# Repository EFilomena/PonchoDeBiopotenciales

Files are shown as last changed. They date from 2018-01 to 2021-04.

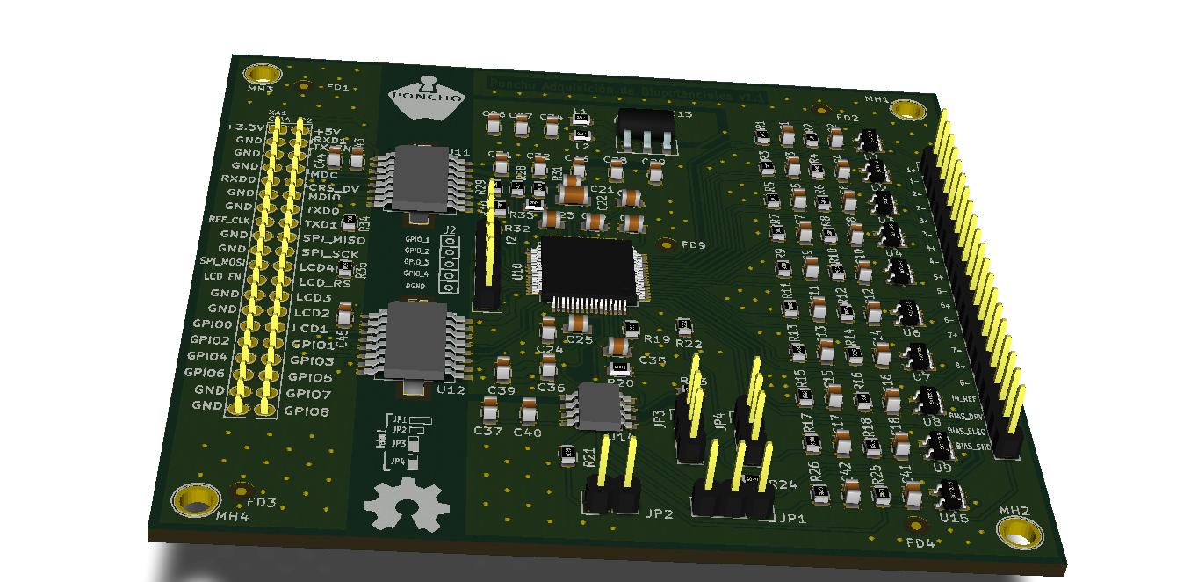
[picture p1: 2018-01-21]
Hardware/doc/PonchoBiopotenciales3d.jpg

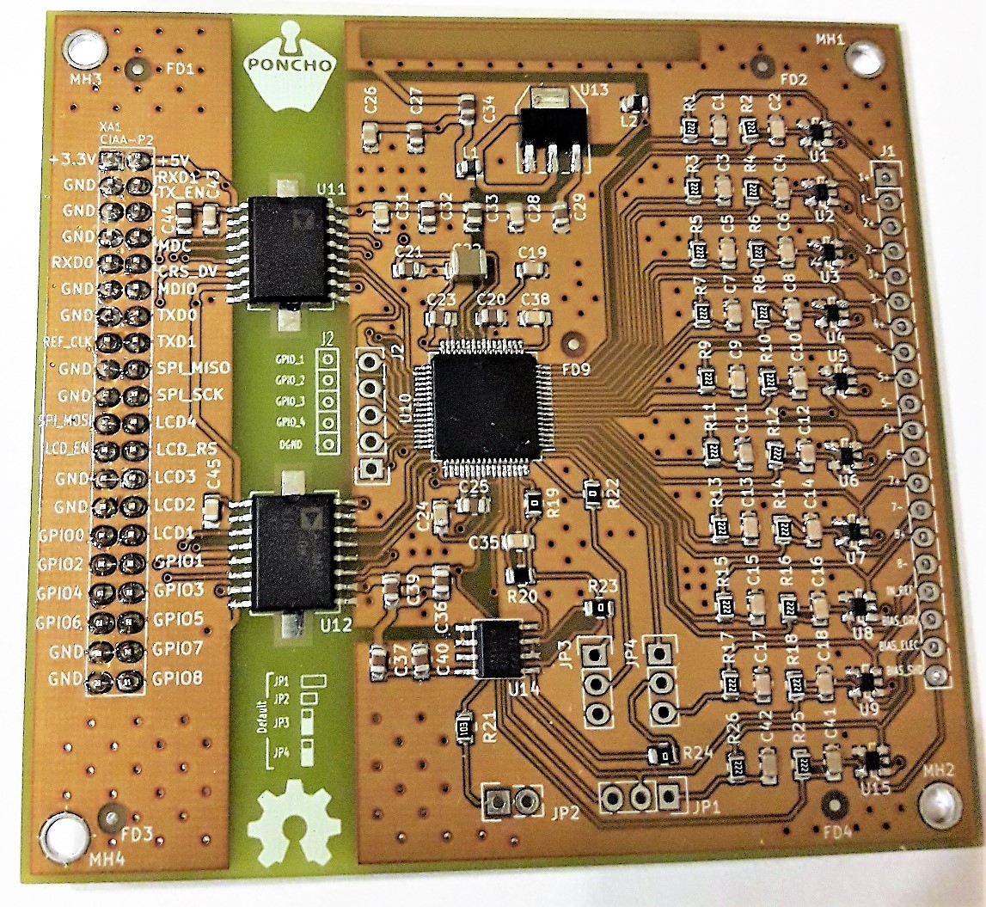
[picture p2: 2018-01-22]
Hardware/doc/Foto1.jpg

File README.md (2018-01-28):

# PonchoDeBiopotenciales

Este repositorio, contiene toda la información de desarrollo del poncho de adquisición de biopotenciales. 
Este poncho es parte del proyecto CIAA (http://www.proyecto-ciaa.com.ar/), y aplica fundamentalmente a la placa 
EDU-CIAA (http://www.proyecto-ciaa.com.ar/devwiki/doku.php?id=desarrollo:edu-ciaa:edu-ciaa-nxp). 

Permite la digitalización y registro de todo tipo de biopotenciales como: electrocardiograma, 
electroencefalograma, electromiograma, electrooculograma entre otros.

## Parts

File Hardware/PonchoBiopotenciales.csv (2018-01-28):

Source | D:/Repositorios/PonchoDeBiopotenciales/Hardware/PonchoBiopotenciales.sch
Kicad Rev | Eeschema 4.0.2-stable
Generated Date | 28/01/2018 7:24
Title | Poncho de AdquisiciÃ³n de Biopotenciales
Company | FIUNER
Revision | 1.1
Date Issue | lun 05 oct 2015
Comment | Bruno Javier Cesario - Gonzalo Cuenca - Eduardo Filomena (FIUNER)
Reference | Value | DescripciÃ³n | Fabricante | Nro de parte | Digikey | Footprint | Library | Library Ref | Cotización Digikey 01/2018
G2 | OSHWA | PonchoBiopotenciales | OSHWA |  |  |  |  |  | por 100 unidades
G1 | Logo_Poncho | PonchoBiopotenciales | Logo_Poncho
R1 | 2.2k | RES SMD 2.2K OHM 5% 1/8W 0805 | Yageo | RC0805JR-072K2L | 311-2.2KARCT-ND | 805 | PonchoBiopotenciales | R_Small | 0,0076
R2 | 2.2k | RES SMD 2.2K OHM 5% 1/8W 0805 | Yageo | RC0805JR-072K2L | 311-2.2KARCT-ND | 805 | PonchoBiopotenciales | R_Small | 0,0076
R4 | 2.2k | RES SMD 2.2K OHM 5% 1/8W 0805 | Yageo | RC0805JR-072K2L | 311-2.2KARCT-ND | 805 | PonchoBiopotenciales | R_Small | 0,0076
R3 | 2.2k | RES SMD 2.2K OHM 5% 1/8W 0805 | Yageo | RC0805JR-072K2L | 311-2.2KARCT-ND | 805 | PonchoBiopotenciales | R_Small | 0,0076
C1 | 1nF | CAP CER 1000PF 50V X7R 0805 | Kemet | C0805C102K5RACTU | 399-1147-1-ND | 805 | PonchoBiopotenciales | C | 0,019
C2 | 1nF | CAP CER 1000PF 50V X7R 0805 | Kemet | C0805C102K5RACTU | 399-1147-1-ND | 805 | PonchoBiopotenciales | C | 0,019
C3 | 1nF | CAP CER 1000PF 50V X7R 0805 | Kemet | C0805C102K5RACTU | 399-1147-1-ND | 805 | PonchoBiopotenciales | C | 0,019
C4 | 1nF | CAP CER 1000PF 50V X7R 0805 | Kemet | C0805C102K5RACTU | 399-1147-1-ND | 805 | PonchoBiopotenciales | C | 0,019
C5 | 1nF | CAP CER 1000PF 50V X7R 0805 | Kemet | C0805C102K5RACTU | 399-1147-1-ND | 805 | PonchoBiopotenciales | C | 0,019
C6 | 1nF | CAP CER 1000PF 50V X7R 0805 | Kemet | C0805C102K5RACTU | 399-1147-1-ND | 805 | PonchoBiopotenciales | C | 0,019
C7 | 1nF | CAP CER 1000PF 50V X7R 0805 | Kemet | C0805C102K5RACTU | 399-1147-1-ND | 805 | PonchoBiopotenciales | C | 0,019
C8 | 1nF | CAP CER 1000PF 50V X7R 0805 | Kemet | C0805C102K5RACTU | 399-1147-1-ND | 805 | PonchoBiopotenciales | C | 0,019
C9 | 1nF | CAP CER 1000PF 50V X7R 0805 | Kemet | C0805C102K5RACTU | 399-1147-1-ND | 805 | PonchoBiopotenciales | C | 0,019
C10 | 1nF | CAP CER 1000PF 50V X7R 0805 | Kemet | C0805C102K5RACTU | 399-1147-1-ND | 805 | PonchoBiopotenciales | C | 0,019
C11 | 1nF | CAP CER 1000PF 50V X7R 0805 | Kemet | C0805C102K5RACTU | 399-1147-1-ND | 805 | PonchoBiopotenciales | C | 0,019
C12 | 1nF | CAP CER 1000PF 50V X7R 0805 | Kemet | C0805C102K5RACTU | 399-1147-1-ND | 805 | PonchoBiopotenciales | C | 0,019
C13 | 1nF | CAP CER 1000PF 50V X7R 0805 | Kemet | C0805C102K5RACTU | 399-1147-1-ND | 805 | PonchoBiopotenciales | C | 0,019
C14 | 1nF | CAP CER 1000PF 50V X7R 0805 | Kemet | C0805C102K5RACTU | 399-1147-1-ND | 805 | PonchoBiopotenciales | C | 0,019
C15 | 1nF | CAP CER 1000PF 50V X7R 0805 | Kemet | C0805C102K5RACTU | 399-1147-1-ND | 805 | PonchoBiopotenciales | C | 0,019
C16 | 1nF | CAP CER 1000PF 50V X7R 0805 | Kemet | C0805C102K5RACTU | 399-1147-1-ND | 805 | PonchoBiopotenciales | C | 0,019
R13 | 2.2k | RES SMD 2.2K OHM 5% 1/8W 0805 | Yageo | RC0805JR-072K2L | 311-2.2KARCT-ND | 805 | PonchoBiopotenciales | R_Small | 0,0076
R14 | 2.2k | RES SMD 2.2K OHM 5% 1/8W 0805 | Yageo | RC0805JR-072K2L | 311-2.2KARCT-ND | 805 | PonchoBiopotenciales | R_Small | 0,0076
R16 | 2.2k | RES SMD 2.2K OHM 5% 1/8W 0805 | Yageo | RC0805JR-072K2L | 311-2.2KARCT-ND | 805 | PonchoBiopotenciales | R_Small | 0,0076
R15 | 2.2k | RES SMD 2.2K OHM 5% 1/8W 0805 | Yageo | RC0805JR-072K2L | 311-2.2KARCT-ND | 805 | PonchoBiopotenciales | R_Small | 0,0076
R17 | 2.2k | RES SMD 2.2K OHM 5% 1/8W 0805 | Yageo | RC0805JR-072K2L | 311-2.2KARCT-ND | 805 | PonchoBiopotenciales | R_Small | 0,0076
R18 | 2.2k | RES SMD 2.2K OHM 5% 1/8W 0805 | Yageo | RC0805JR-072K2L | 311-2.2KARCT-ND | 805 | PonchoBiopotenciales | R_Small | 0,0076
C17 | 1nF | CAP CER 1000PF 50V X7R 0805 | Kemet | C0805C102K5RACTU | 399-1147-1-ND | 805 | PonchoBiopotenciales | C | 0,019
C18 | 1nF | CAP CER 1000PF 50V X7R 0805 | Kemet | C0805C102K5RACTU | 399-1147-1-ND | 805 | PonchoBiopotenciales | C | 0,019
U1 | TPD2E001 | TVS DIODE 5.5VWM 100VC SOT5 | Texas Instruments | TPD2E001DRLR | 296-21883-1-ND | SOT-553 | PonchoBiopotenciales | TPD2E001 | 0,37
U2 | TPD2E001 | TVS DIODE 5.5VWM 100VC SOT5 | Texas Instruments | TPD2E001DRLR | 296-21883-1-ND | SOT-553 | PonchoBiopotenciales | TPD2E001 | 0,37
U3 | TPD2E001 | TVS DIODE 5.5VWM 100VC SOT5 | Texas Instruments | TPD2E001DRLR | 296-21883-1-ND | SOT-553 | PonchoBiopotenciales | TPD2E001 | 0,37
U4 | TPD2E001 | TVS DIODE 5.5VWM 100VC SOT5 | Texas Instruments | TPD2E001DRLR | 296-21883-1-ND | SOT-553 | PonchoBiopotenciales | TPD2E001 | 0,37
U5 | TPD2E001 | TVS DIODE 5.5VWM 100VC SOT5 | Texas Instruments | TPD2E001DRLR | 296-21883-1-ND | SOT-553 | PonchoBiopotenciales | TPD2E001 | 0,37
U6 | TPD2E001 | TVS DIODE 5.5VWM 100VC SOT5 | Texas Instruments | TPD2E001DRLR | 296-21883-1-ND | SOT-553 | PonchoBiopotenciales | TPD2E001 | 0,37
U7 | TPD2E001 | TVS DIODE 5.5VWM 100VC SOT5 | Texas Instruments | TPD2E001DRLR | 296-21883-1-ND | SOT-553 | PonchoBiopotenciales | TPD2E001 | 0,37
U8 | TPD2E001 | TVS DIODE 5.5VWM 100VC SOT5 | Texas Instruments | TPD2E001DRLR | 296-21883-1-ND | SOT-553 | PonchoBiopotenciales | TPD2E001 | 0,37
U9 | TPD2E001 | TVS DIODE 5.5VWM 100VC SOT5 | Texas Instruments | TPD2E001DRLR | 296-21883-1-ND | SOT-553 | PonchoBiopotenciales | TPD2E001 | 0,37
U15 | TPD2E001 | TVS DIODE 5.5VWM 100VC SOT5 | Texas Instruments | TPD2E001DRLR | 296-21883-1-ND | SOT-553 | PonchoBiopotenciales | TPD2E001 | 0,37
R26 | 2.2k | RES SMD 2.2K OHM 5% 1/8W 0805 | Yageo | RC0805JR-072K2L | 311-2.2KARCT-ND | 805 | PonchoBiopotenciales | R_Small | 0,0076
R25 | 2.2k | RES SMD 2.2K OHM 5% 1/8W 0805 | Yageo | RC0805JR-072K2L | 311-2.2KARCT-ND | 805 | PonchoBiopotenciales | R_Small | 0,0076
C41 | 1nF | CAP CER 1000PF 50V X7R 0805 | Kemet | C0805C102K5RACTU | 399-1147-1-ND | 805 | PonchoBiopotenciales | C | 0,019
C42 | 1nF | CAP CER 1000PF 50V X7R 0805 | Kemet | C0805C102K5RACTU | 399-1147-1-ND | 805 | PonchoBiopotenciales | C | 0,019
J1 | 20POS SIL VERTICAL PIN HEADER | Cuttable Connector 0.100" (2.54mm) Through Hole Tin | Harwin Inc. | M20-9992046 | 952-1902-ND |  | PonchoBiopotenciales | CONN_01X20 | 0,45
R12 | 2.2k | RES SMD 2.2K OHM 5% 1/8W 0805 | Yageo | RC0805JR-072K2L | 311-2.2KARCT-ND | 805 | PonchoBiopotenciales | R_Small | 0,0076
R11 | 2.2k | RES SMD 2.2K OHM 5% 1/8W 0805 | Yageo | RC0805JR-072K2L | 311-2.2KARCT-ND | 805 | PonchoBiopotenciales | R_Small | 0,0076
R10 | 2.2k | RES SMD 2.2K OHM 5% 1/8W 0805 | Yageo | RC0805JR-072K2L | 311-2.2KARCT-ND | 805 | PonchoBiopotenciales | R_Small | 0,0076
R8 | 2.2k | RES SMD 2.2K OHM 5% 1/8W 0805 | Yageo | RC0805JR-072K2L | 311-2.2KARCT-ND | 805 | PonchoBiopotenciales | R_Small | 0,0076
R7 | 2.2k | RES SMD 2.2K OHM 5% 1/8W 0805 | Yageo | RC0805JR-072K2L | 311-2.2KARCT-ND | 805 | PonchoBiopotenciales | R_Small | 0,0076
R6 | 2.2k | RES SMD 2.2K OHM 5% 1/8W 0805 | Yageo | RC0805JR-072K2L | 311-2.2KARCT-ND | 805 | PonchoBiopotenciales | R_Small | 0,0076
R5 | 2.2k | RES SMD 2.2K OHM 5% 1/8W 0805 | Yageo | RC0805JR-072K2L | 311-2.2KARCT-ND | 805 | PonchoBiopotenciales | R_Small | 0,0076
R9 | 2.2k | RES SMD 2.2K OHM 5% 1/8W 0805 | Yageo | RC0805JR-072K2L | 311-2.2KARCT-ND | 805 | PonchoBiopotenciales | R_Small | 0,0076
U10 | ADS1299 | IC AFE 8-CH 24BIT 64TQFP | Texas Instruments | ADS1299IPAG | 296-35009-ND | 64-TQFP | PonchoBiopotenciales | ADS1299 | 46,48
C19 | 0.1uF | CAP CER 0.1UF 50V X7R 0805 | Kemet | C0805C104J5RACTU | 399-1171-1-ND | 0805 (2012 Metric) | PonchoBiopotenciales | C | 0,06
C20 | 10uF | CAP CER 10UF 25V X5R 0805 | Murata Electronics North America | GRM219R61E106KA12D | 490-7207-1-ND | 0805 (2012 Metric) | PonchoBiopotenciales | C | 0,1
C21 | 1uF | CAP CER 1UF 16V X7R 0805 | Kemet | C0805C105K4RACTU | 399-1284-1-ND | 0805 (2012 Metric) | PonchoBiopotenciales | C | 0,04
C23 | 1uF | CAP CER 1UF 16V X7R 0805 | Kemet | C0805C105K4RACTU | 399-1284-1-ND | 0805 (2012 Metric) | PonchoBiopotenciales | C | 0,04
C22 | 100uF | CAP CER 100UF 10V X5R 1210 | Kemet | C1210C107M8PACTU | 399-11631-1-ND | 1210 (3225 Metric) | PonchoBiopotenciales | C | 0,78
C24 | 0.1uF | CAP CER 0.1UF 50V X7R 0805 | Kemet | C0805C104J5RACTU | 399-1171-1-ND | 0805 (2012 Metric) | PonchoBiopotenciales | C | 0,06
C25 | 1uF | CAP CER 1UF 16V X7R 0805 | Kemet | C0805C105K4RACTU | 399-1284-1-ND | 0805 (2012 Metric) | PonchoBiopotenciales | C | 0,04
C26 | 0.1uF | CAP CER 0.1UF 50V X7R 0805 | Kemet | C0805C104J5RACTU | 399-1171-1-ND | 0805 (2012 Metric) | PonchoBiopotenciales | C | 0,06
C27 | 1uF | CAP CER 1UF 16V X7R 0805 | Kemet | C0805C105K4RACTU | 399-1284-1-ND | 0805 (2012 Metric) | PonchoBiopotenciales | C | 0,04
C28 | 0.1uF | CAP CER 0.1UF 50V X7R 0805 | Kemet | C0805C104J5RACTU | 399-1171-1-ND | 0805 (2012 Metric) | PonchoBiopotenciales | C | 0,06
C29 | 1uF | CAP CER 1UF 16V X7R 0805 | Kemet | C0805C105K4RACTU | 399-1284-1-ND | 0805 (2012 Metric) | PonchoBiopotenciales | C | 0,06
R19 | 0 | RES SMD 0 OHM JUMPER 1/8W 0805 | Yageo | RC0805JR-070RL | 311-0.0ARCT-ND | 0805 (2012 Metric) | PonchoBiopotenciales | R_Small | 0,007
R20 | 390k | RES SMD 390K OHM 5% 1/8W 0805 | Yageo | RC0805JR-07390KL | 311-390KARCT-ND | 0805 (2012 Metric) | PonchoBiopotenciales | R_Small | 0,007
C35 | 0.01uF | CAP CER 10000PF 50V X7R 0805 | Kemet | C0805C103K5RACTU | 399-1158-1-ND | 0805 (2012 Metric) | PonchoBiopotenciales | C | 0,017
JP2 | JUMPER | CONN HEADER VERT SGL 20POS GOLD | 3M | 961120-6404-AR | 3M9457-20-ND |  | PonchoBiopotenciales | JUMPER | 1,2
JP1 | JUMPER3 | CONN HEADER VERT SGL 20POS GOLD | 3M | 961120-6404-AR | 3M9457-20-ND |  | PonchoBiopotenciales | JUMPER3 | 1,2
U14 | OPA2376 | IC OPAMP GP 5.5MHZ RRO 8SOIC | Texas Instruments | OPA2376AIDR | 296-22564-1-ND | 8-SOIC (0.154" 3.90mm Width) | PonchoBiopotenciales | OPA2376 | 1,8
R21 | 10k | RES SMD 10K OHM 5% 1/8W 0805 | Yageo | RC0805JR-0710KL | 311-10KARCT-ND | 0805 (2012 Metric) | PonchoBiopotenciales | R_Small | 0,07
C36 | 1uF | CAP CER 1UF 16V X7R 0805 | Kemet | C0805C105K4RACTU | 399-1284-1-ND | 0805 (2012 Metric) | PonchoBiopotenciales | C | 0,07
C37 | 1uF | CAP CER 1UF 16V X7R 0805 | Kemet | C0805C105K4RACTU | 399-1284-1-ND | 0805 (2012 Metric) | PonchoBiopotenciales | C | 0,07
JP3 | JUMPER3 | CONN HEADER VERT SGL 20POS GOLD | 3M | 961120-6404-AR | 3M9457-20-ND |  | PonchoBiopotenciales | JUMPER3 | 1,2
R23 | 0 | RES SMD 0 OHM JUMPER 1/8W 0805 | Yageo | RC0805JR-070RL | 311-0.0ARCT-ND | 0805 (2012 Metric) | PonchoBiopotenciales | R_Small | 0,007
R22 | 0 | RES SMD 0 OHM JUMPER 1/8W 0805 | Yageo | RC0805JR-070RL | 311-0.0ARCT-ND | 0805 (2012 Metric) | PonchoBiopotenciales | R_Small | 0,007
C38 | 1nF | CAP CER 1000PF 50V X7R 0805 | Kemet | C0805C102K5RACTU | 399-1147-1-ND | 0805 (2012 Metric) | PonchoBiopotenciales | C | 0,019
R24 | 0 | RES SMD 0 OHM JUMPER 1/8W 0805 | Yageo | RC0805JR-070RL | 311-0.0ARCT-ND | 0805 (2012 Metric) | PonchoBiopotenciales | R_Small | 0,007
JP4 | JUMPER3 | CONN HEADER VERT SGL 20POS GOLD | 3M | 961120-6404-AR | 3M9457-20-ND |  | PonchoBiopotenciales | JUMPER3 | 1,2
C39 | 1uF | CAP CER 1UF 16V X7R 0805 | Kemet | C0805C105K4RACTU | 399-1284-1-ND | 0805 (2012 Metric) | PonchoBiopotenciales | C | 0,06
C40 | 1uF | CAP CER 1UF 16V X7R 0805 | Kemet | C0805C105K4RACTU | 399-1284-1-ND | 0805 (2012 Metric) | PonchoBiopotenciales | C | 0,06
J2 | IOs MultipropÃ³sito | CONN HEADER VERT SGL 20POS GOLD | 3M | 961120-6404-AR | 3M9457-20-ND |  | PonchoBiopotenciales | CONN_01X05 | 1,2
Jumper_STD1 | J_STD | PonchoBiopotenciales | J_STD
Jumper_Config1 | J_CFG | PonchoBiopotenciales | J_CFG
C31 | 0.1uF | CAP CER 0.1UF 50V X7R 0805 | Kemet | C0805C104J5RACTU | 399-1171-1-ND | 0805 (2012 Metric) | PonchoBiopotenciales | C | 0,06
C32 | 10uF | CAP CER 10UF 25V X5R 0805 | Murata Electronics North America | GRM219R61E106KA12D | 490-7207-1-ND | 0805 (2012 Metric) | PonchoBiopotenciales | C | 0,06
U11 | ADuM6401 | DGTL ISO 5KV 4CH GEN PURP 16SOIC | Analog Devices Inc | ADUM6401CRWZ | ADUM6401CRWZ-ND | 16-SOIC (0.295" 7.50mm Width) | PonchoBiopotenciales | ADuM6401-RESCUE-PonchoERG | 14,6
U12 | ADuM2401 | DGTL ISO 5KV 4CH GEN PURP 16SOIC | Analog Devices Inc. | ADUM2401ARWZ-RL | ADUM2401ARWZ-RLCT-ND | 16-SOIC (0.295" 7.50mm Width) | PonchoBiopotenciales | ADuM2401 | 5,99
XA1 | Conn_Poncho2P_2x_20x2 | CONN HEADER .100" DUAL STR 40POS | Sullins Connector Solutions | PRPC020DAAN-RC | S2011EC-20-ND |  | PonchoBiopotenciales | Conn_Poncho2P_2x_20x2 | 0,68
C43 | 0.1uF | CAP CER 0.1UF 50V X7R 0805 | Kemet | C0805C104J5RACTU | 399-1171-1-ND | 0805 (2012 Metric) | PonchoBiopotenciales | C | 0,06
C44 | 10uF | CAP CER 10UF 25V X5R 0805 | Murata Electronics North America | GRM219R61E106KA12D | 490-7207-1-ND | 0805 (2012 Metric) | PonchoBiopotenciales | C | 0,06
C45 | 0.1uF | CAP CER 0.1UF 50V X7R 0805 | Kemet | C0805C104J5RACTU | 399-1171-1-ND | 0805 (2012 Metric) | PonchoBiopotenciales | C | 0,06
SC_2 | Slot_2 | PonchoBiopotenciales | Fiducial
SC_1 | Slot_1 | PonchoBiopotenciales | Fiducial
R28 | 1k | RES SMD 1K OHM 5% 1/8W 0805 | Yageo | RC0805JR-071KL | 311-1.0KARCT-ND | 0805 (2012 Metric) | PonchoBiopotenciales | R_Small | 0,007
R29 | 1k | RES SMD 1K OHM 5% 1/8W 0805 | Yageo | RC0805JR-071KL | 311-1.0KARCT-ND | 0805 (2012 Metric) | PonchoBiopotenciales | R_Small | 0,007
R30 | 1k | RES SMD 1K OHM 5% 1/8W 0805 | Yageo | RC0805JR-071KL | 311-1.0KARCT-ND | 0805 (2012 Metric) | PonchoBiopotenciales | R_Small | 0,007
R31 | 1.8k | RES SMD 1.8K OHM 5% 1/8W 0805 | Yageo | RC0805JR-071K8L | 311-1.8KARCT-ND | 0805 (2012 Metric) | PonchoBiopotenciales | R_Small | 0,007
R32 | 1.8k | RES SMD 1.8K OHM 5% 1/8W 0805 | Yageo | RC0805JR-071K8L | 311-1.8KARCT-ND | 0805 (2012 Metric) | PonchoBiopotenciales | R_Small | 0,007
R35 | 1.8k | RES SMD 1.8K OHM 5% 1/8W 0805 | Yageo | RC0805JR-071K8L | 311-1.8KARCT-ND | 0805 (2012 Metric) | PonchoBiopotenciales | R_Small | 0,007
R34 | 1k | RES SMD 1K OHM 5% 1/8W 0805 | Yageo | RC0805JR-071KL | 311-1.0KARCT-ND | 0805 (2012 Metric) | PonchoBiopotenciales | R_Small | 0,007
R33 | 1.8k | RES SMD 1.8K OHM 5% 1/8W 0805 | Yageo | RC0805JR-071K8L | 311-1.8KARCT-ND | 0805 (2012 Metric) | PonchoBiopotenciales | R_Small | 0,007
U13 | NCP1117ST33T3G | IC REG LINEAR 3.3V 1A SOT223 | ON Semiconductor | NCP1117ST33T3G | NCP1117ST33T3GOSCT-ND | SOT-223 | PonchoBiopotenciales | NCP1117ST33T3G | 0,3
L1 | HZ0805E601R-10 | FERRITE BEAD 600 OHM 0805 1LN | Laird-Signal Integrity Products | HZ0805E601R-10 | 240-2399-1-ND | 0805 (2012 Metric) | PonchoBiopotenciales | HZ0805E601R-10 | 0,04
L2 | HZ0805E601R-10 | FERRITE BEAD 600 OHM 0805 1LN | Laird-Signal Integrity Products | HZ0805E601R-10 | 240-2399-1-ND | 0805 (2012 Metric) | PonchoBiopotenciales | HZ0805E601R-10 | 0,04
C33 | 10uF | CAP CER 10UF 25V X5R 0805 | Murata Electronics North America | GRM219R61E106KA12D | 490-7207-1-ND | 0805 (2012 Metric) | PonchoBiopotenciales | C | 0,1
C34 | 10uF | CAP CER 10UF 25V X5R 0805 | Murata Electronics North America | GRM219R61E106KA12D | 490-7207-1-ND | 0805 (2012 Metric) | PonchoBiopotenciales | C | 0,1
FD8 | Fiducial | PonchoBiopotenciales | Fiducial
FD7 | Fiducial | PonchoBiopotenciales | Fiducial |  |  |  |  |  | 82,909
FD6 | Fiducial | PonchoBiopotenciales | Fiducial
FD5 | Fiducial | PonchoBiopotenciales | Fiducial
FD9 | Fiducial | PonchoBiopotenciales | Fiducial
MH1 | PCB_HOLE | PonchoBiopotenciales | PCB_HOLE
MH4 | PCB_HOLE | PonchoBiopotenciales | PCB_HOLE
MH3 | PCB_HOLE | PonchoBiopotenciales | PCB_HOLE
MH2 | PCB_HOLE | PonchoBiopotenciales | PCB_HOLE
FD4 | Fiducial | PonchoBiopotenciales | Fiducial
FD3 | Fiducial | PonchoBiopotenciales | Fiducial
FD2 | Fiducial | PonchoBiopotenciales | Fiducial
FD1 | Fiducial | PonchoBiopotenciales | Fiducial

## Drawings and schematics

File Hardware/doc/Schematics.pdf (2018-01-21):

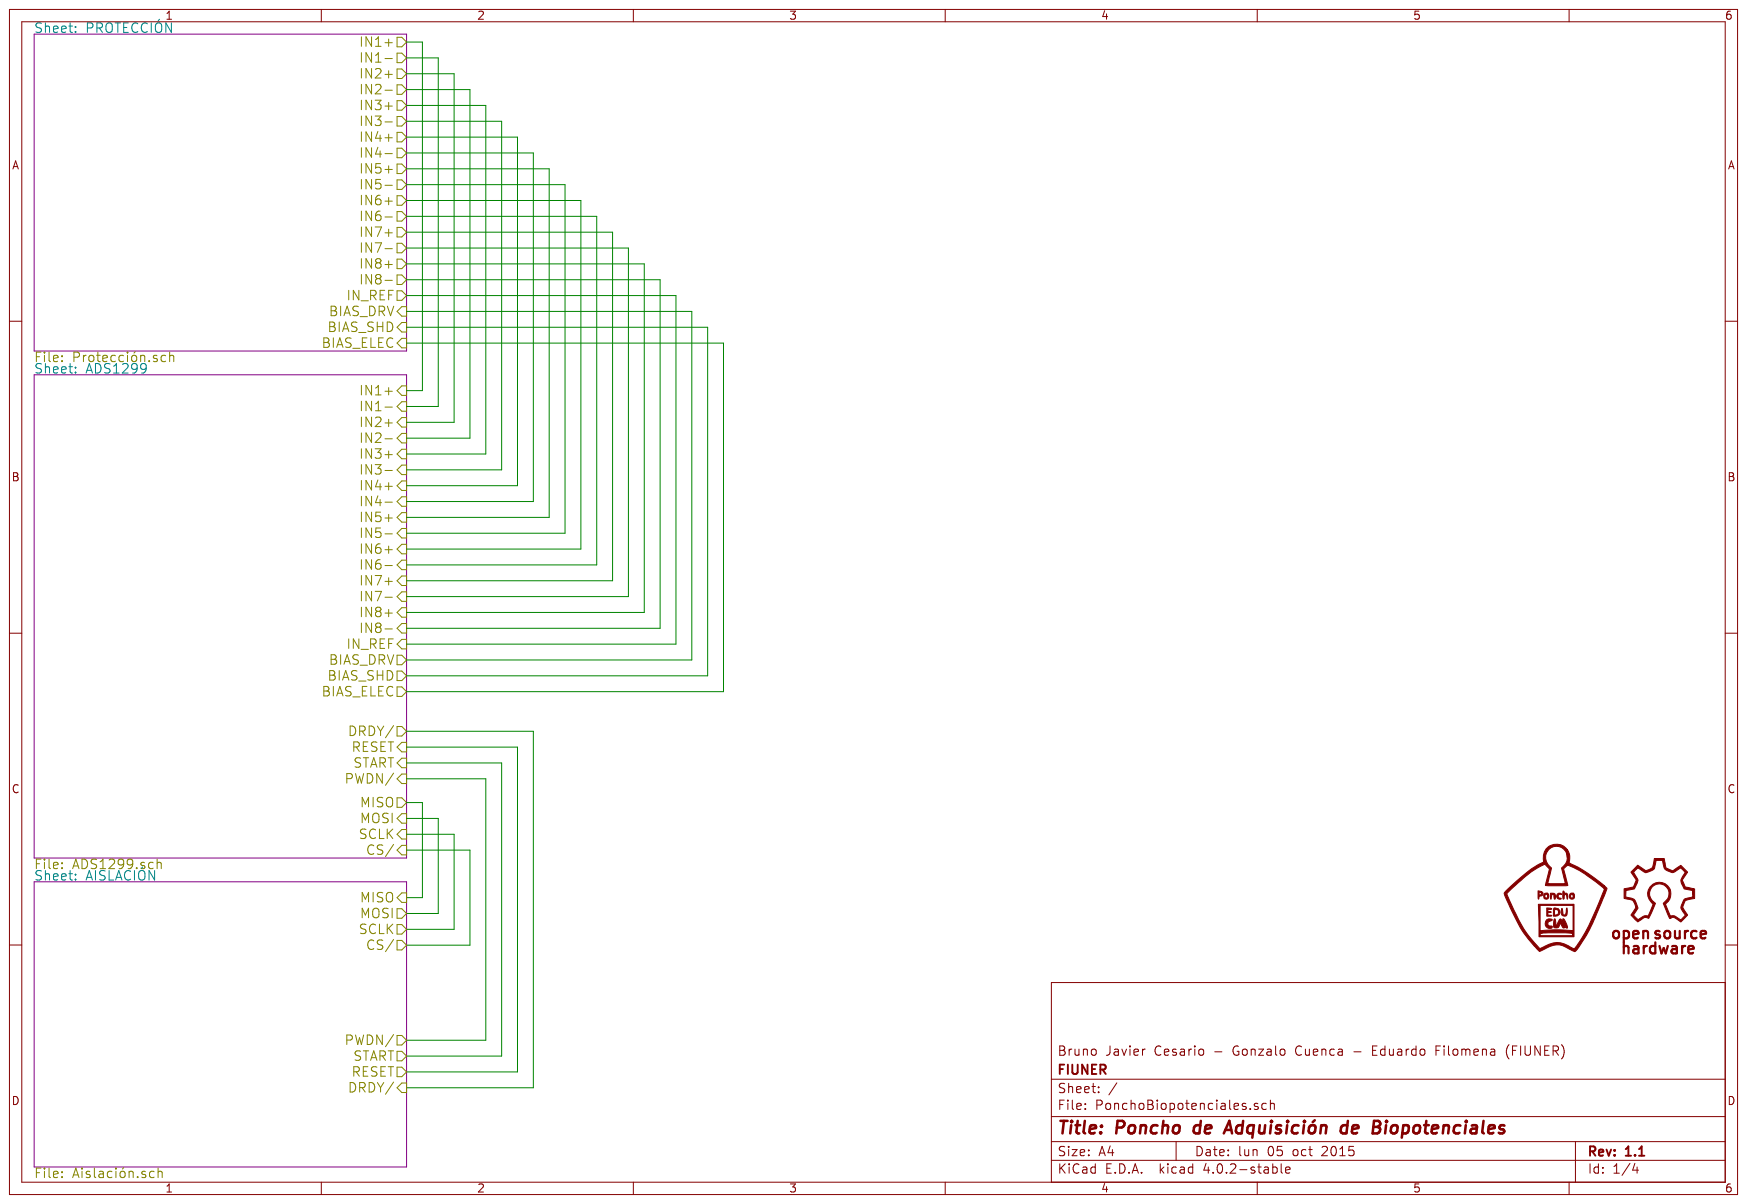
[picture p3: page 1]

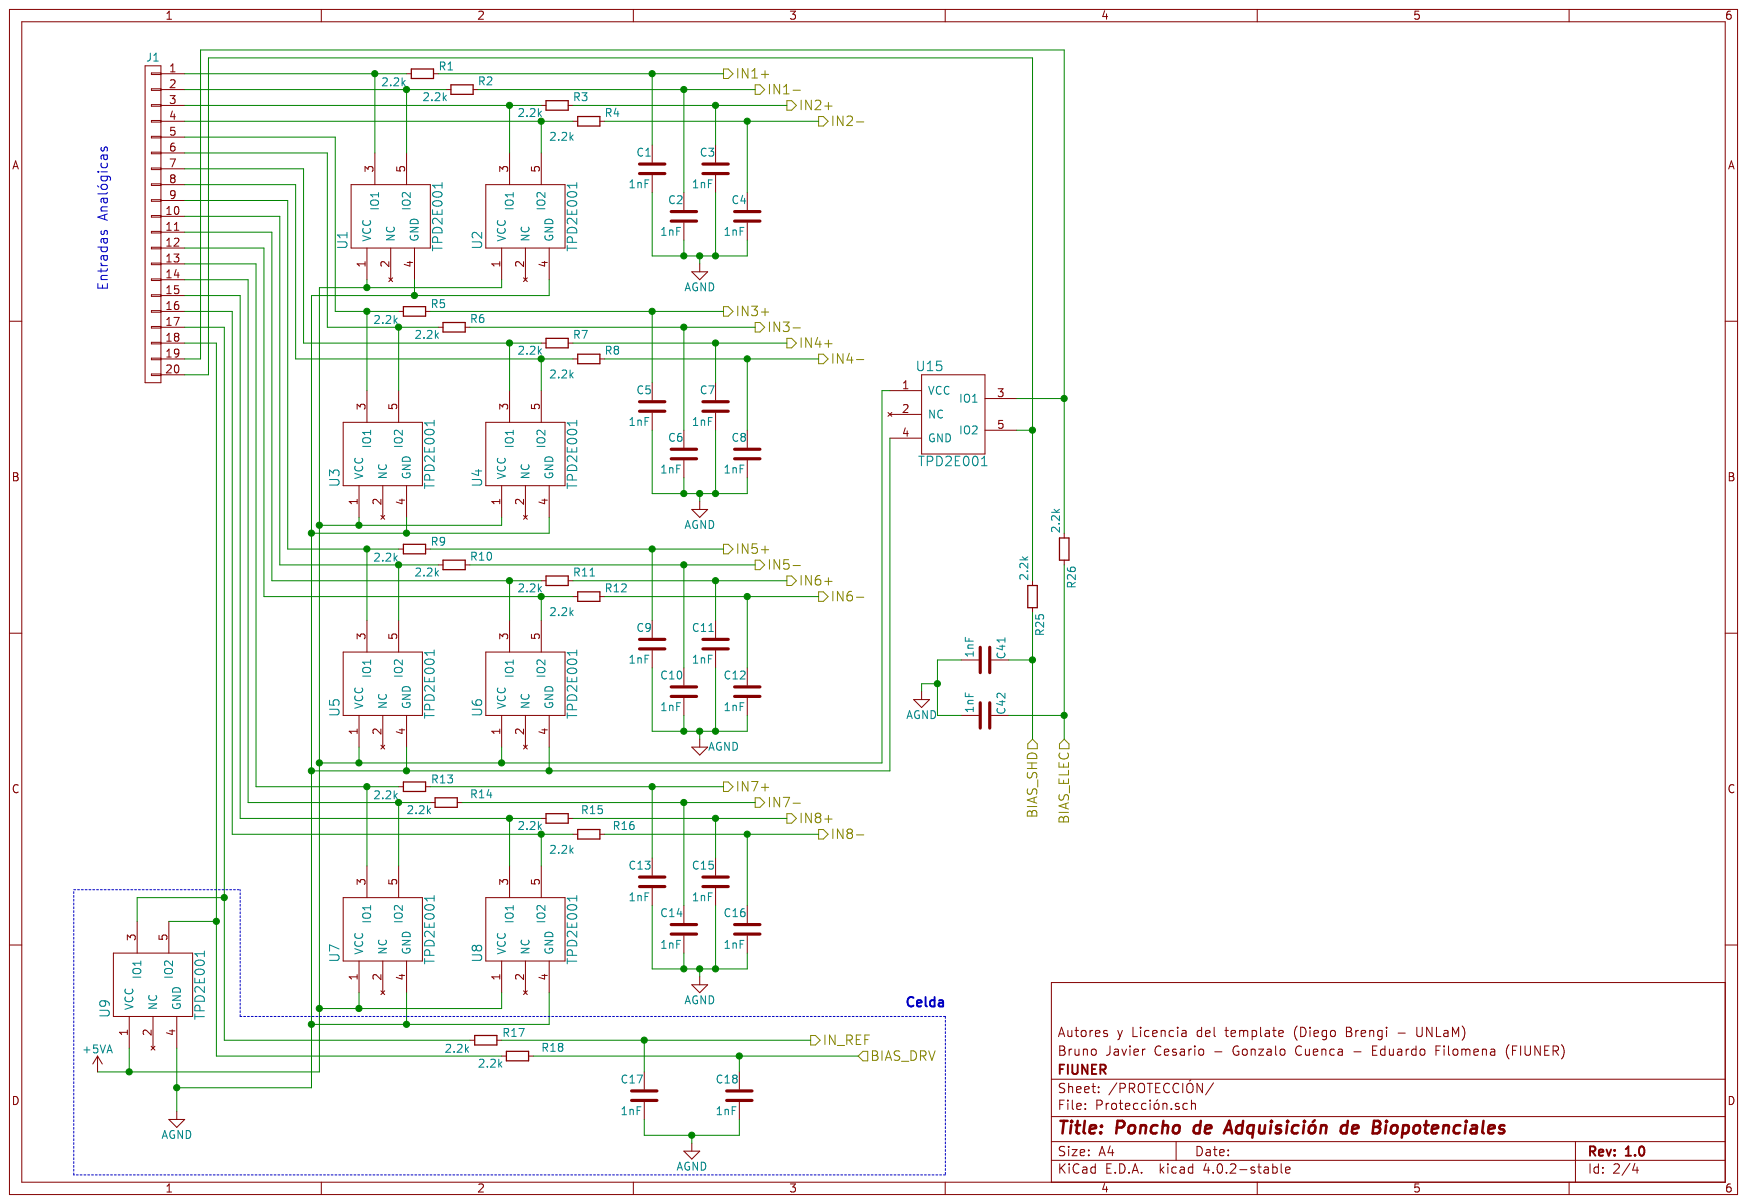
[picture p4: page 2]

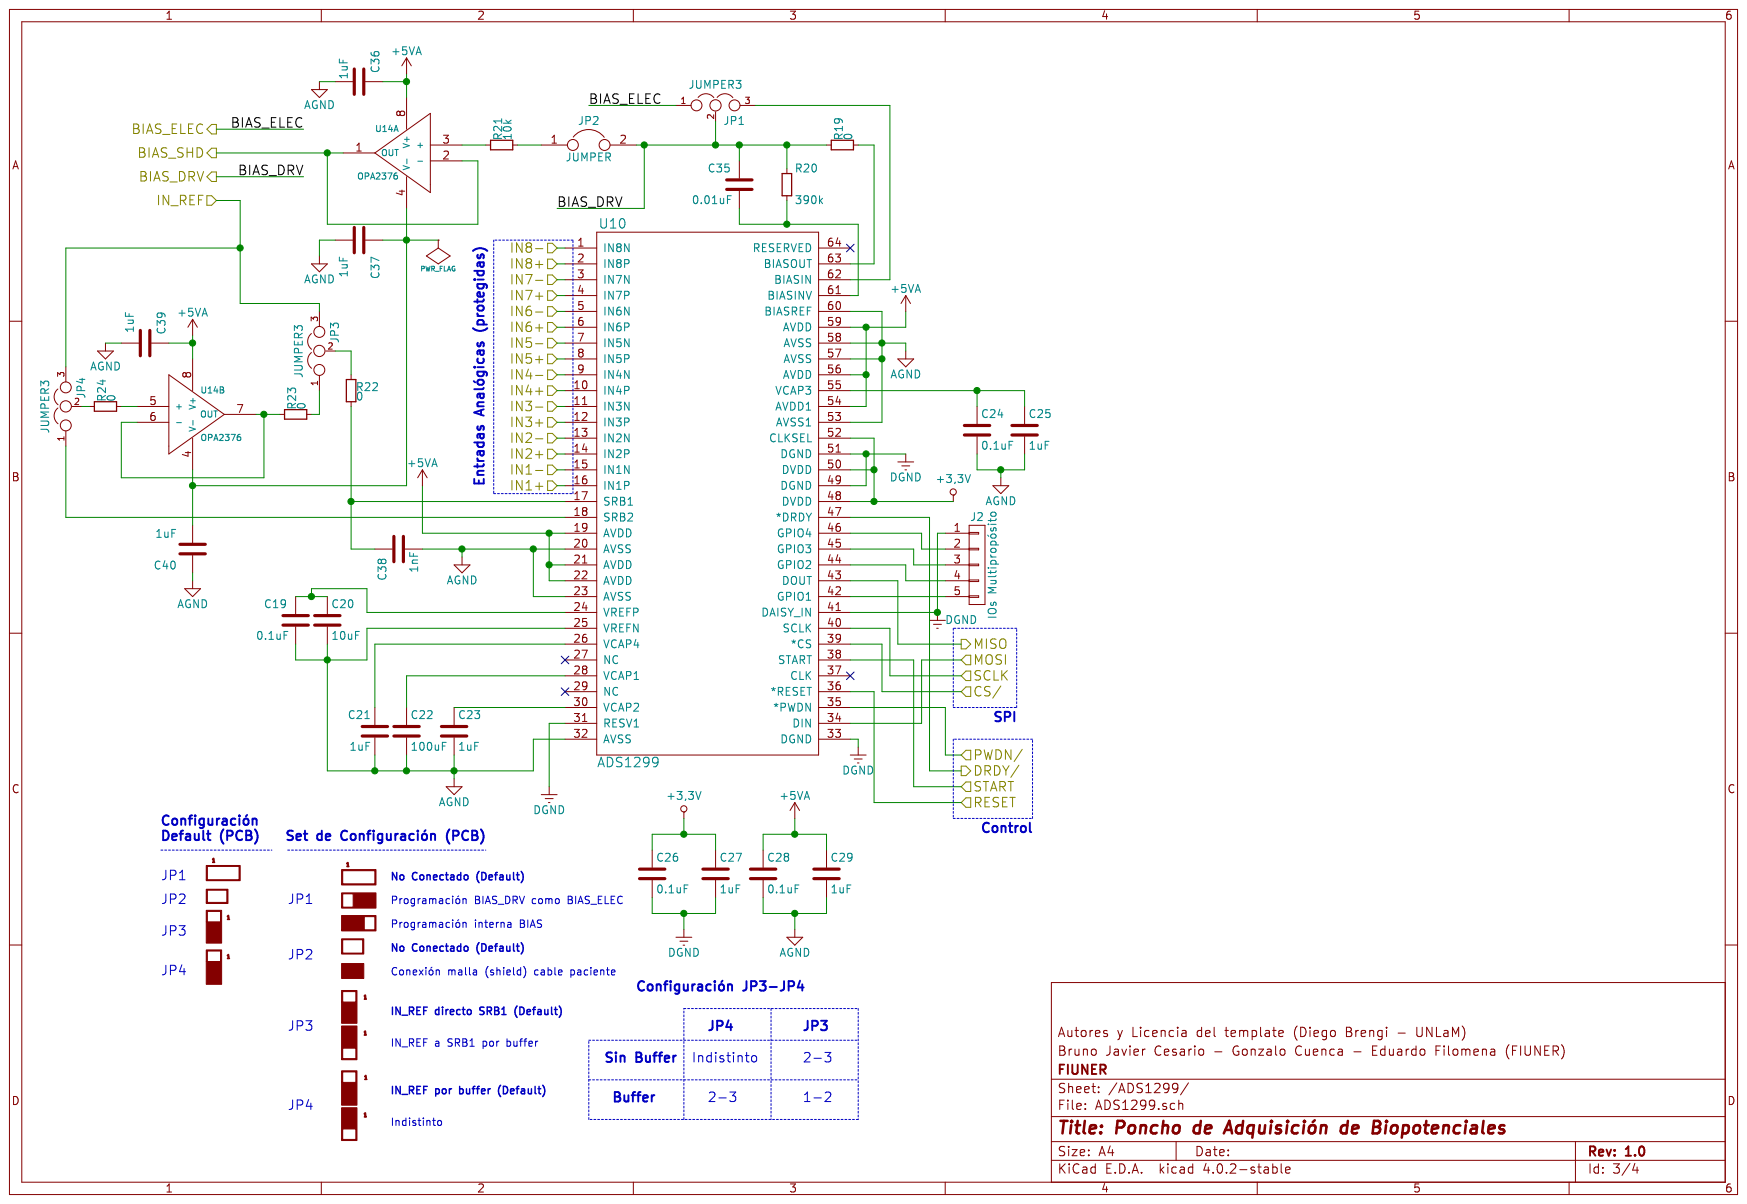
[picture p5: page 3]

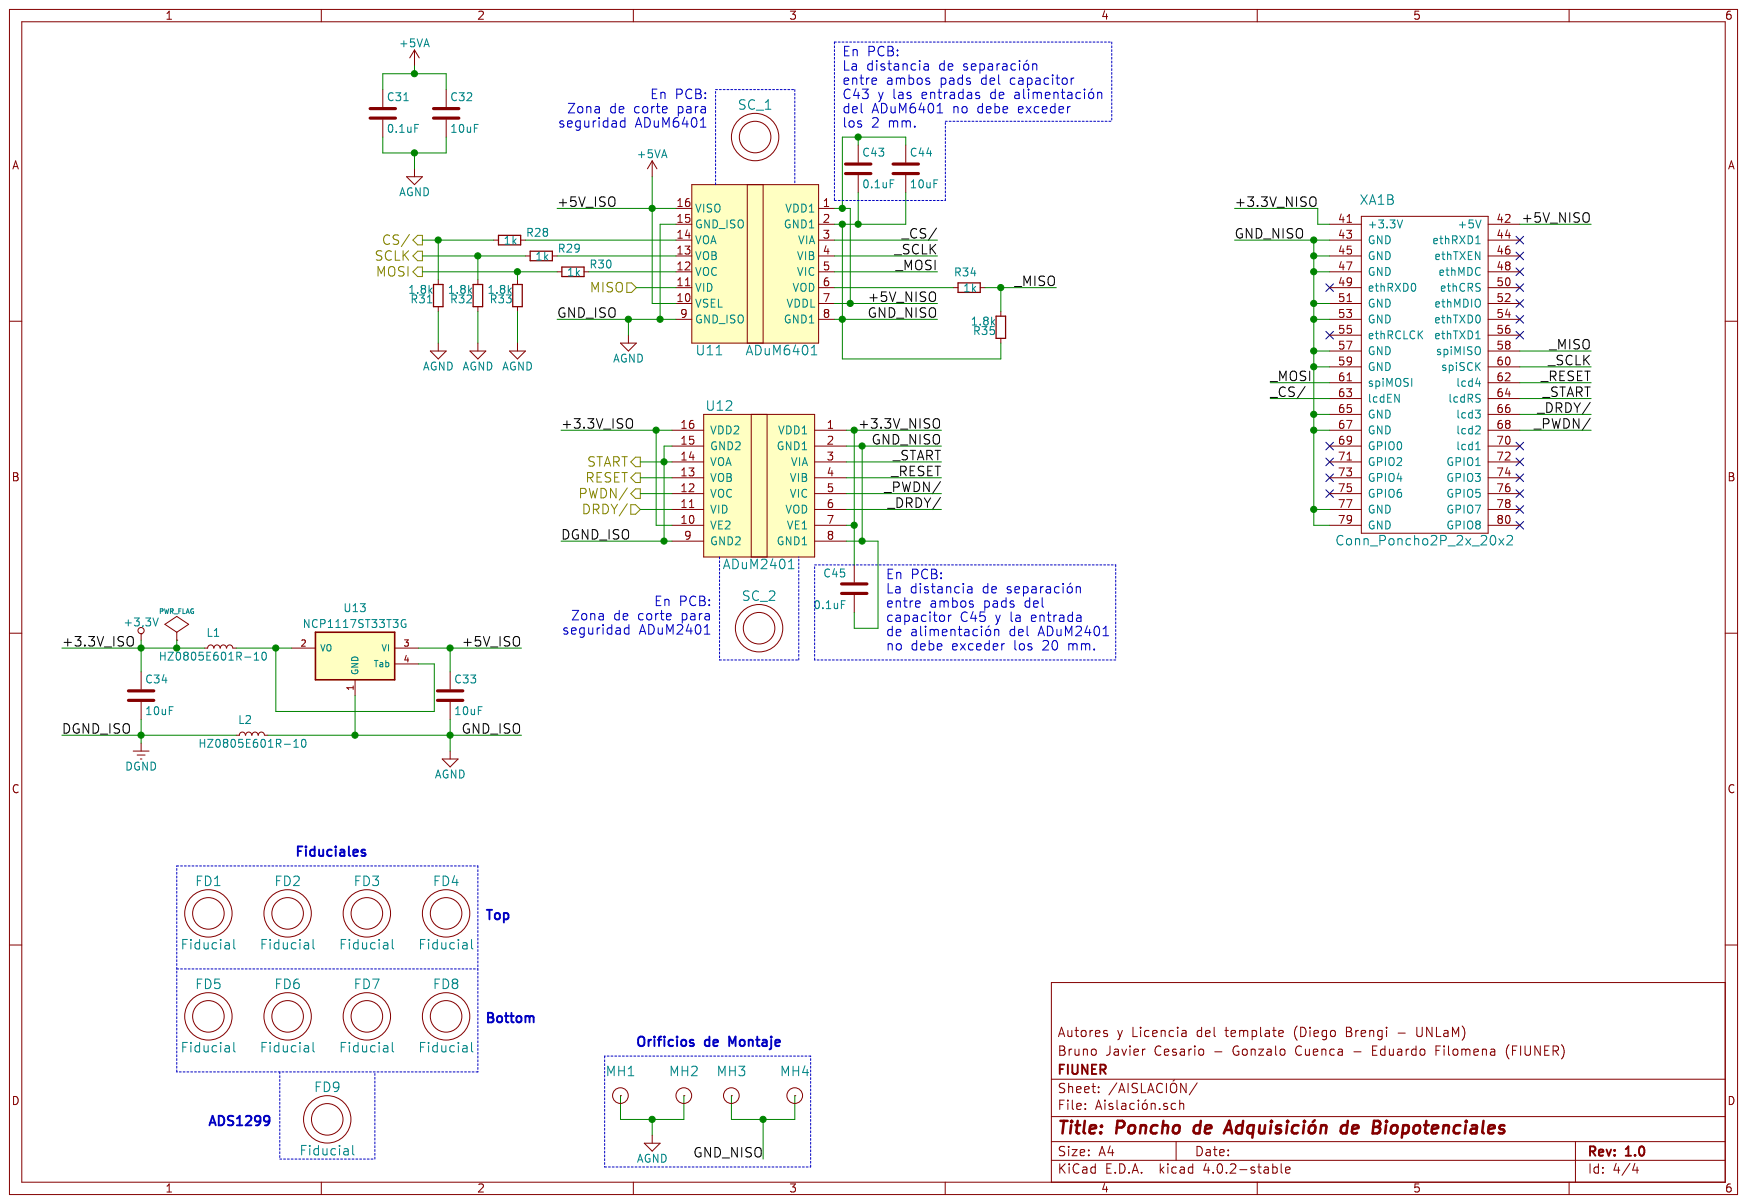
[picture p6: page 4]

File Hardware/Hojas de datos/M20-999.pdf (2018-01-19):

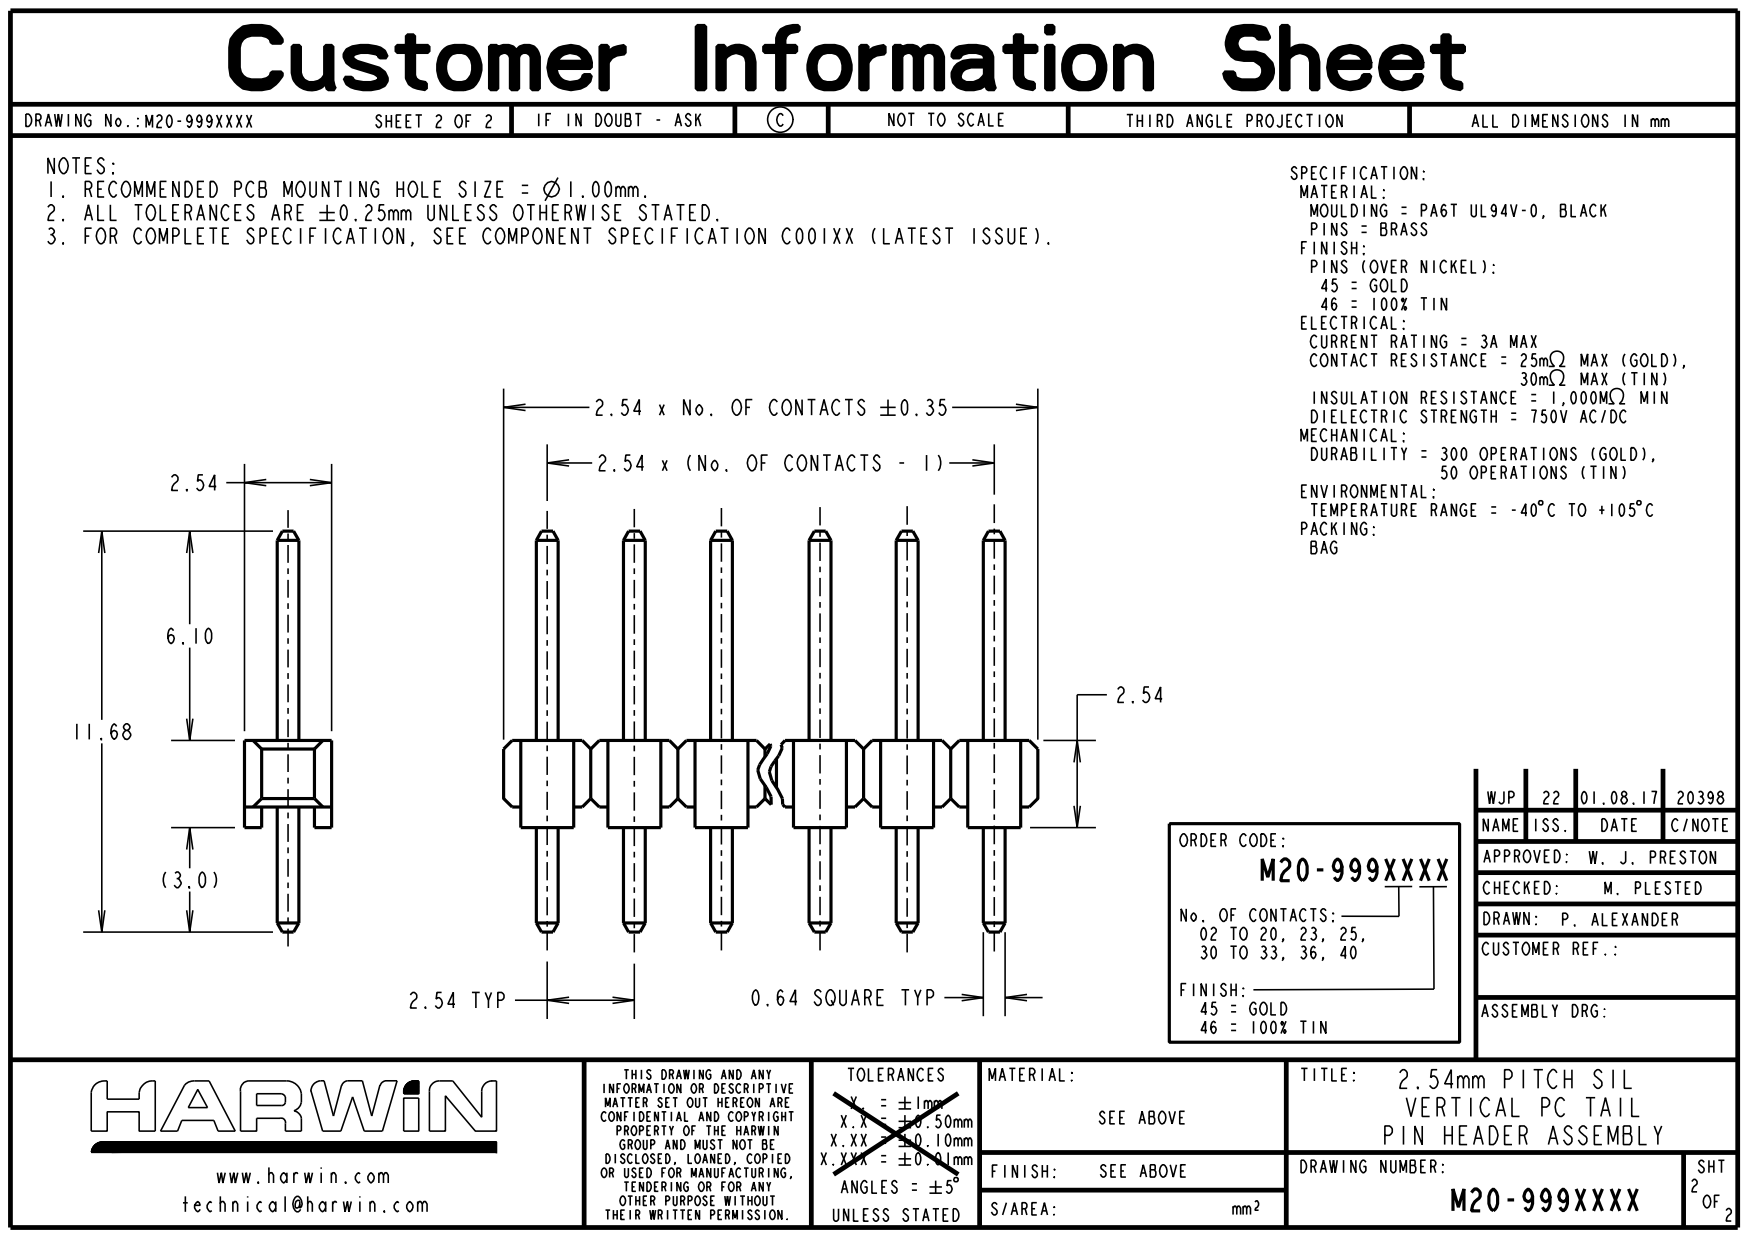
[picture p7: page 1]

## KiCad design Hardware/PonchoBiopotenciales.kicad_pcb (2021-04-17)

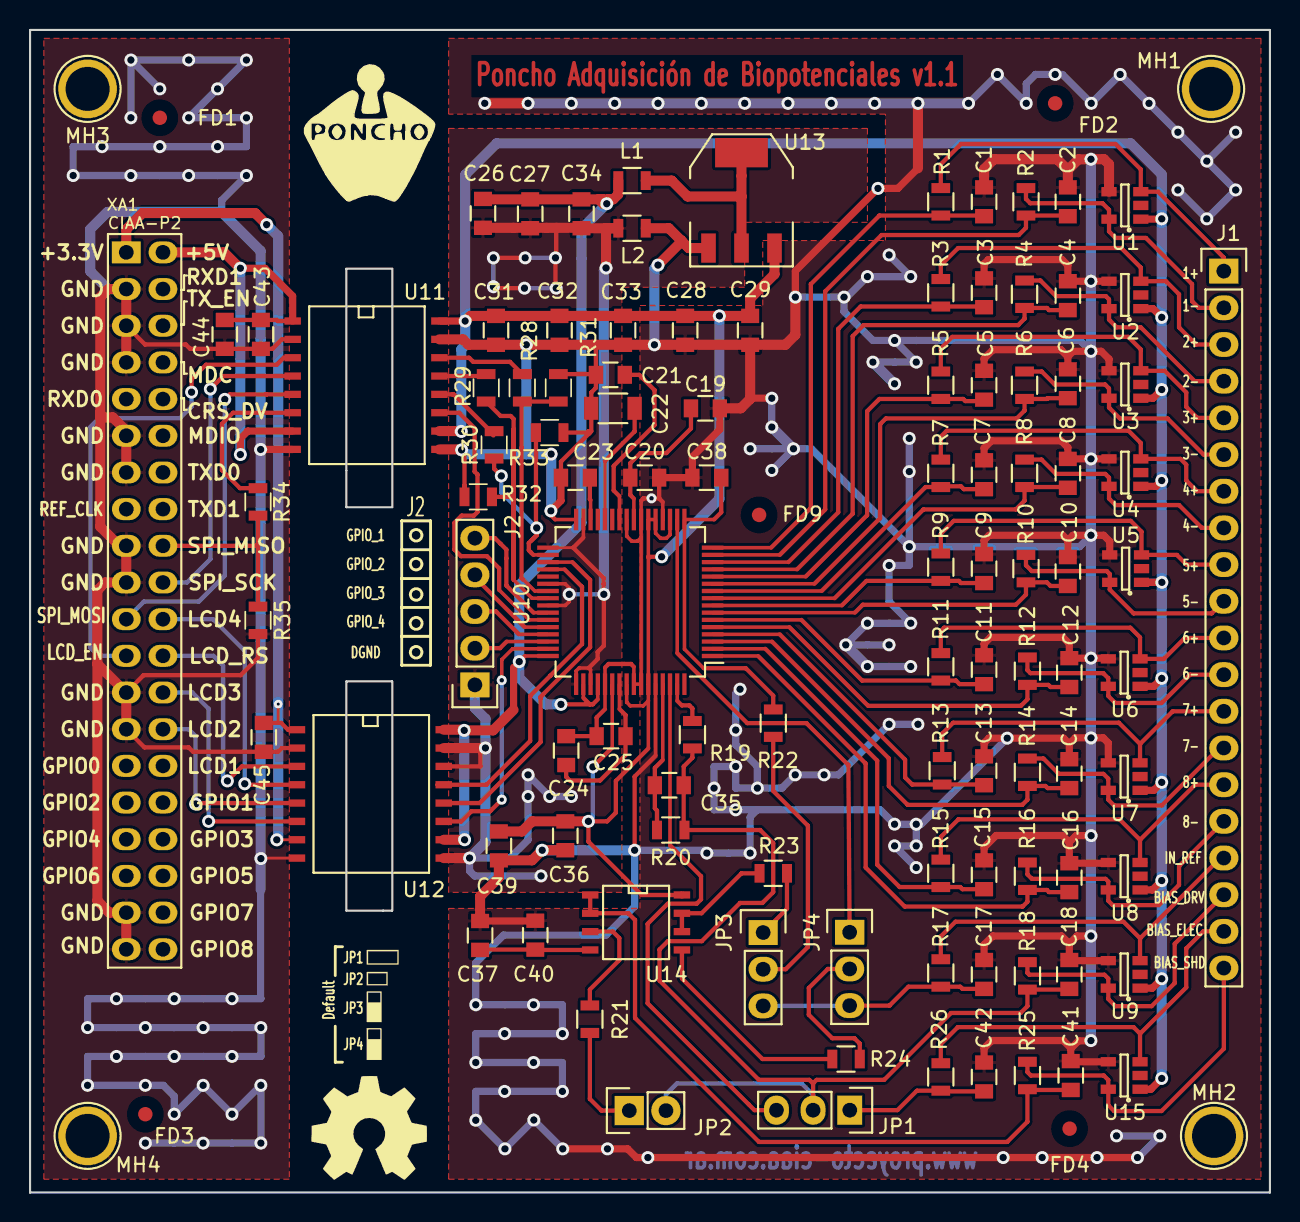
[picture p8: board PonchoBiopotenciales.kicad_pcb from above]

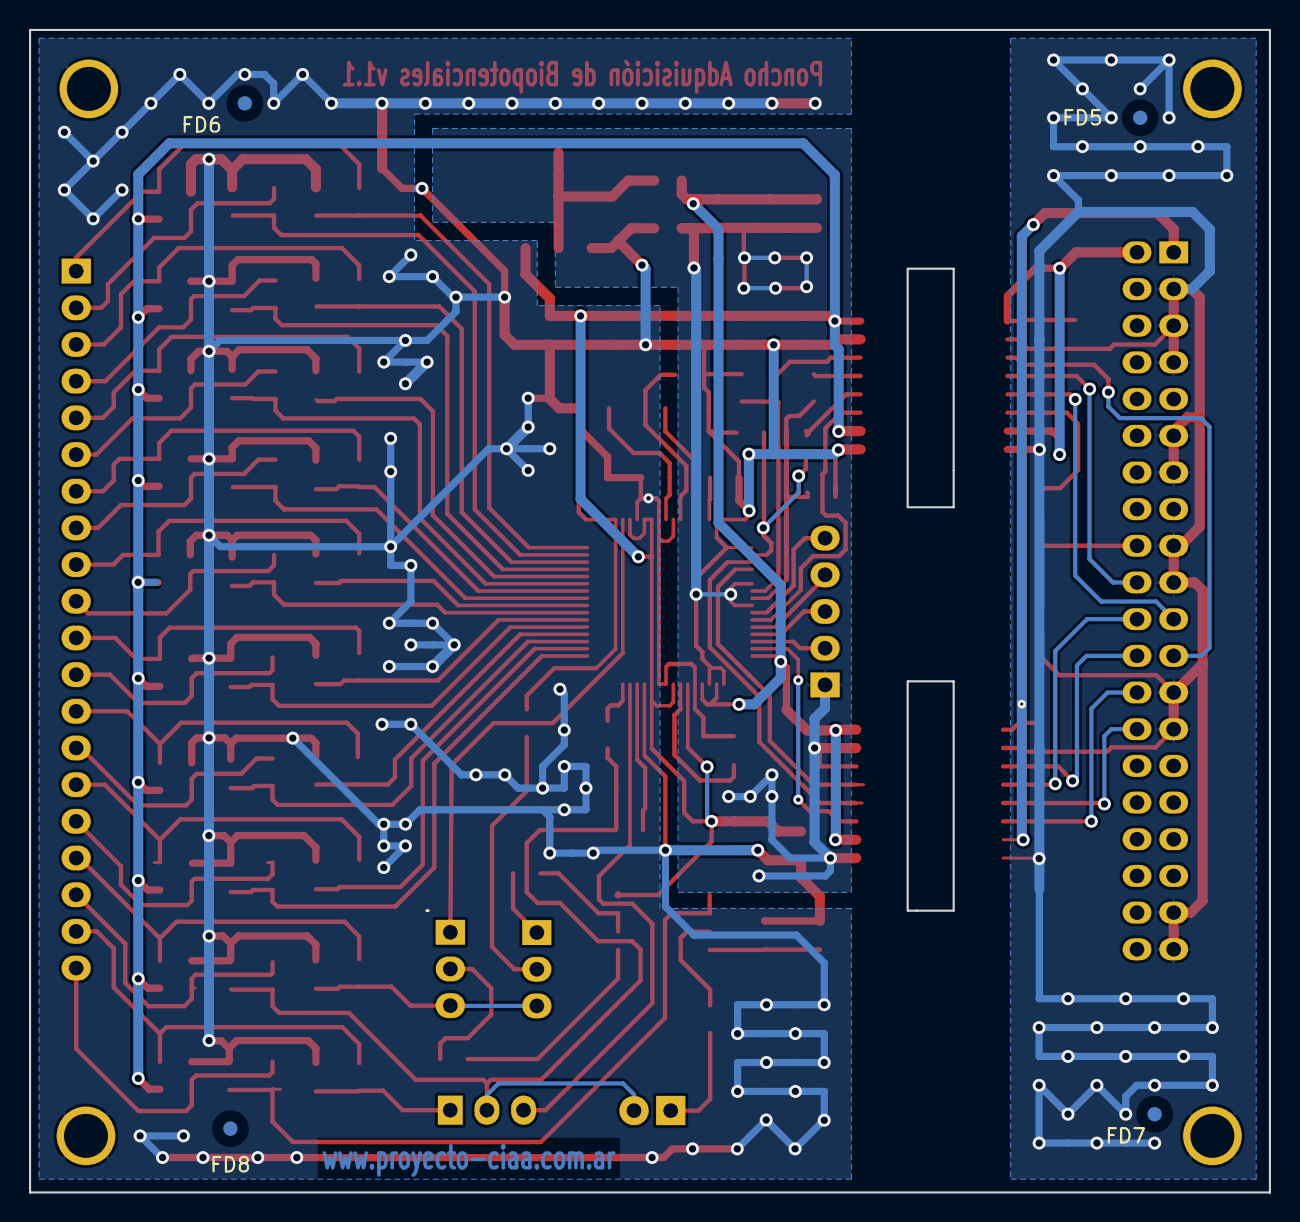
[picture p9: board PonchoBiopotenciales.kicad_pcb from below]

Board: 2 copper layers, 85.9 x 80.5 mm, 118 parts (4 on the bottom side), 89 nets.

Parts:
C1, C2, C3, C4, C5, C6, C7, C8, C9, C10, C11, C12, C13, C14, C15, C16, C17, C18, C38, C41, C42: 1nF; C_0805
C19, C24, C26, C28, C31, C43, C45: 0.1uF; C_0805
C20, C32, C33, C34, C44: 10uF; C_0805
C21, C23, C25, C27, C29, C36, C37, C39, C40: 1uF; C_0805
C22: 100uF; C_1206
C35: 0.01uF; C_0805
FD1, FD2, FD3, FD4, FD5, FD6, FD7, FD8, FD9: Fiducial; Fiducial_1mm_Dia_2.54mm_Outer_CopperTop
G1: Logo_Poncho
G2: OSHWA; Logo_OSHWA
J1: Entradas Analógicas; Pin_Header_Straight_1x20
J2: IOs Multipropósito; Pin_Header_Straight_1x05
JP1, JP3, JP4: JUMPER3; Pin_Header_Straight_1x03
JP2: JUMPER; Pin_Header_Straight_1x02
Jumper_STD1: J_STD; Jumpers_Default
L1, L2: HZ0805E601R-10; R_0805
MH1, MH2, MH3, MH4: PCB_HOLE; 1pin
R1, R2, R3, R4, R5, R6, R7, R8, R9, R10, R11, R12, R13, R14, R15, R16, R17, R18, R25, R26: 2.2k; R_0805
R19, R22, R23, R24: 0; R_0805
R20: 390k; R_0805
R21: 10k; R_0805
R28, R29, R30, R34: 1k; R_0805
R31, R32, R33, R35: 1.8k; R_0805
U1, U2, U3, U4, U5, U6, U7, U8, U9, U15: TPD2E001; SOT-23-5
U10: ADS1299; TQFP-64_10x10mm_Pitch0.5mm
U11: ADuM6401; SO-16-W
U12: ADuM2401; SO-16-W
U13: NCP1117ST33T3G; SOT-223
U14: OPA2376; SOIC-8-N
XA1: Conn_Poncho2P_2x_20x2; Conn_Poncho_Izquierdo

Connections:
+3.3V: C26.1, C27.1, C34.1, L1.1, U10.48, U10.50, U10.52, U12.10, U12.16
+5VA: C28.1, C29.1, C31.1, C32.1, C33.1, C36.1, C39.1, U1.1, U2.1, U3.1, U4.1, U5.1, U6.1, U7.1, U8.1, U9.1, U10.19, U10.21, U10.22, U10.54, U10.56, U10.59, U11.10, U11.16, U13.3, U14.8, U15.1
/ADS1299/BIAS_DRV: C18.1, C35.1, JP1.2, JP2.2, R18.1, R19.1, R20.1
/ADS1299/BIAS_ELEC: C42.1, JP1.1, R26.2
/ADS1299/BIAS_SHD: C41.1, R25.2, U14.1, U14.2
/ADS1299/CS/: R28.1, R31.2, U10.39
/ADS1299/DRDY/: U10.47, U12.11
/ADS1299/IN1+: C1.1, R1.2, U10.16
/ADS1299/IN1-: C2.1, R2.1, U10.15
/ADS1299/IN2+: C3.1, R3.1, U10.14
/ADS1299/IN2-: C4.1, R4.1, U10.13
/ADS1299/IN3+: C5.1, R5.2, U10.12
/ADS1299/IN3-: C6.1, R6.1, U10.11
/ADS1299/IN4+: C7.1, R7.1, U10.10
/ADS1299/IN4-: C8.1, R8.1, U10.9
/ADS1299/IN5+: C9.1, R9.2, U10.8
/ADS1299/IN5-: C10.1, R10.1, U10.7
/ADS1299/IN6+: C11.1, R11.1, U10.6
/ADS1299/IN6-: C12.1, R12.1, U10.5
/ADS1299/IN7+: C13.1, R13.2, U10.4
/ADS1299/IN7-: C14.1, R14.1, U10.3
/ADS1299/IN8+: C15.1, R15.1, U10.2
/ADS1299/IN8-: C16.1, R16.1, U10.1
/ADS1299/IN_REF: C17.1, JP3.3, JP4.3, R17.2
/ADS1299/MISO: U10.43, U11.11
/ADS1299/MOSI: R30.1, R33.2, U10.34
/ADS1299/PWDN/: U10.35, U12.12
/ADS1299/RESET: U10.36, U12.13
/ADS1299/SCLK: R29.1, R32.2, U10.40
/AISLACIÓN/+3.3V_NISO: C45.2, U12.1, U12.7, XA1.41
/AISLACIÓN/+5V_NISO: C43.1, C44.1, U11.1, U11.7, XA1.42
/AISLACIÓN/GND_NISO: C43.2, C44.2, C45.1, MH3.1, MH4.1, R35.1, U11.2, U11.8, U12.2, U12.8, XA1.43, XA1.45, XA1.47, XA1.51, XA1.53, XA1.57, XA1.59, XA1.65, XA1.67, XA1.77, XA1.79
/AISLACIÓN/_CS/: U11.3, XA1.63
/AISLACIÓN/_DRDY/: U12.6, XA1.66
/AISLACIÓN/_MISO: R34.2, R35.2, XA1.58
/AISLACIÓN/_MOSI: U11.5, XA1.61
/AISLACIÓN/_PWDN/: U12.5, XA1.68
/AISLACIÓN/_RESET: U12.4, XA1.62
/AISLACIÓN/_SCLK: U11.4, XA1.60
/AISLACIÓN/_START: U12.3, XA1.64
DGND: C26.2, C27.2, C34.2, J2.1, L2.1, U10.31, U10.33, U10.38, U10.41, U10.49, U10.51, U12.9, U12.14, U12.15
GNDA: C1.2, C2.2, C3.2, C4.2, C5.2, C6.2, C7.2, C8.2, C9.2, C10.2, C11.2, C12.2, C13.2, C14.2, C15.2, C16.2, C17.2, C18.2, C19.2, C20.2, C21.2, C22.2, C23.2, C24.2, C25.2, C28.2, C29.2, C31.2, C32.2, C33.2, C36.2, C37.2, C38.2, C39.2, C40.1, C41.2, C42.2, L2.2, MH1.1, MH2.1, R31.1, R32.1, R33.1, U1.4, U2.4, U3.4, U4.4, U5.4, U6.4, U7.4, U8.4, U9.4, U10.20, U10.23, U10.25, U10.32, U10.53, U10.57, U10.58, U10.60, U11.9, U11.15, U13.1, U15.4
unnamed: C19.1, C20.1, U10.24
unnamed: C21.1, U10.26
unnamed: C22.1, U10.28
unnamed: C23.1, U10.30
unnamed: C24.1, C25.1, U10.55
unnamed: C35.2, R20.2, U10.61
unnamed: C37.1, C40.2, U14.4
unnamed: C38.1, R22.2, U10.17
unnamed: J1.1, R1.1, U1.3
unnamed: J1.2, R2.2, U1.5
unnamed: J1.3, R3.2, U2.3
unnamed: J1.4, R4.2, U2.5
unnamed: J1.5, R5.1, U3.3
unnamed: J1.6, R6.2, U3.5
unnamed: J1.7, R7.2, U4.3
unnamed: J1.8, R8.2, U4.5
unnamed: J1.9, R9.1, U5.3
unnamed: J1.10, R10.2, U5.5
unnamed: J1.11, R11.2, U6.3
unnamed: J1.12, R12.2, U6.5
unnamed: J1.13, R13.1, U7.3
unnamed: J1.14, R14.2, U7.5
unnamed: J1.15, R15.2, U8.3
unnamed: J1.16, R16.2, U8.5
unnamed: J1.17, R17.1, U9.3
unnamed: J1.18, R18.2, U9.5
unnamed: J1.19, R26.1, U15.3
unnamed: J1.20, R25.1, U15.5
unnamed: J2.2, U10.46
unnamed: J2.3, U10.45
unnamed: J2.4, U10.44
unnamed: J2.5, U10.42
unnamed: JP1.3, U10.62
unnamed: JP2.1, R21.2
unnamed: JP3.1, R23.2
unnamed: JP3.2, R22.1
unnamed: JP4.1, U10.18
unnamed: JP4.2, R24.1
unnamed: L1.2, U13.2, U13.4
unnamed: R19.2, U10.63
unnamed: R21.1, U14.3
unnamed: R23.1, U14.6, U14.7
unnamed: R24.2, U14.5
unnamed: R28.2, U11.14
unnamed: R29.2, U11.13
unnamed: R30.2, U11.12
unnamed: R34.1, U11.6

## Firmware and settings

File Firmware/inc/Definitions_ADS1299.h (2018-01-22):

/*
 * Definitions_ADS1299.h
 *
 *  Created on: 9/11/2015
 *      Author: alumno
 */

#ifndef DEFINITIONS_ADS1299_H_
#define DEFINITIONS_ADS1299_H_

/** @defgroup Definitions_ADS1299
 *  @ingroup "Biopoteciales-LIRINS"
 *  Set of definitions used for controlling the ADS1299.
 *  @{
 */

//PIN CONNECTIONS
#define ADS_DRDY_PIN	6	// ADS data ready pin
#define ADS_DRDY_PORT	2	// ADS data ready port

#define ADS_RST_PIN	    14	// ADS reset pin
#define ADS_RST_PORT	5	// ADS reset port

#define ADS_START_PIN	12	// ADS start pin
#define ADS_START_PORT	5	// ADS start port

#define BOARD_ADS_PIN	13 //Master ADS chip select pin
#define BOARD_ADS_PORT  5  //Master ADS chip select port

#define ADS_PWDN_PIN	5  //Master ADS chip select pin
#define ADS_PWDN_PORT   2  //Master ADS chip select port


#define SLAVE_ADS_PIN	28 // Slave ADS chip select pin
#define SLAVE_ADS_PORT  1  //Slave ADS chip select port

#define BOARD_ADS	1 	// ADS chip select
#define SLAVE_ADS	2   // ADS Daisy chip select
#define BOTH_ADS	3	// Slave Select Both ADS chips


//ADS1299 SPI Command Definition Byte Assignments
#define _WAKEUP 0x02 // Wake-up from standby mode
#define _STANDBY 0x04 // Enter Standby mode
#define _RESET 0x06 // Reset the device registers to default
#define _START 0x08 // Start and restart (synchronize) conversions
#define _STOP 0x0A // Stop conversion
#define _RDATAC 0x10 // Enable Read Data Continuous mode (default mode at power-up)
#define _SDATAC 0x11 // Stop Read Data Continuous mode
#define _RDATA 0x12 // Read data by command; supports multiple read back

//ASD1299 Register Addresses
#define ADS_ID	0x3E	// product ID for ADS1299
#define ID_REG  0x00	// this register contains ADS_ID
#define CONFIG1 0x01
#define CONFIG2 0x02
#define CONFIG3 0x03
#define LOFF 0x04
#define CH1SET 0x05
#define CH2SET 0x06
#define CH3SET 0x07
#define CH4SET 0x08
#define CH5SET 0x09
#define CH6SET 0x0A
#define CH7SET 0x0B
#define CH8SET 0x0C
#define BIAS_SENSP 0x0D
#define BIAS_SENSN 0x0E
#define LOFF_SENSP 0x0F
#define LOFF_SENSN 0x10
#define LOFF_FLIP 0x11
#define LOFF_STATP 0x12
#define LOFF_STATN 0x13
#define GPIO_ 0x14
#define MISC1 0x15
#define MISC2 0x16
#define CONFIG4 0x17

#define OUTPUT_NOTHING (0)  // quiet
#define OUTPUT_8_CHAN (1)   // not using Daisy module
#define OUTPUT_16_CHAN (2)  // using Daisy module
#define ON_BOARD	(8)			  // slave address for on board ADS
#define ON_DAISY	(3)				// slave address for daisy ADS
// CHANNEL SETTINGS
#define POWER_DOWN_     (0)
#define GAIN_SET        (1)
#define INPUT_TYPE_SET  (2)
#define BIAS_SET        (3)
#define SRB2_SET        (4)
#define SRB1_SET        (5)
#define YES      	(0x01)
#define NO      	(0x00)

//gainCode choices
#define ADS_GAIN01 (0b00000000)	// 0x00
#define ADS_GAIN02 (0b00010000)	// 0x10
#define ADS_GAIN04 (0b00100000)	// 0x20
#define ADS_GAIN06 (0b00110000)	// 0x30
#define ADS_GAIN08 (0b01000000)	// 0x40
#define ADS_GAIN12 (0b01010000)	// 0x50
#define ADS_GAIN24 (0b01100000)	// 0x60

//inputType choices
#define ADSINPUT_NORMAL (0b00000000)
#define ADSINPUT_SHORTED (0b00000001)
#define ADSINPUT_BIAS_MEAS (0b00000010)
#define ADSINPUT_MVDD (0b00000011)
#define ADSINPUT_TEMP (0b00000100)
#define ADSINPUT_TESTSIG (0b00000101)
#define ADSINPUT_BIAS_DRP (0b00000110)
#define ADSINPUT_BIAL_DRN (0b00000111)

//test signal choices...ADS1299 datasheet page 41
#define ADSTESTSIG_AMP_1X (0b00000000)
#define ADSTESTSIG_AMP_2X (0b00000100)
#define ADSTESTSIG_PULSE_SLOW (0b00000000)
#define ADSTESTSIG_PULSE_FAST (0b00000001)
#define ADSTESTSIG_DCSIG (0b00000011)
#define ADSTESTSIG_NOCHANGE (0b11111111)

//Lead-off signal choices
#define LOFF_MAG_6NA (0b00000000)
#define LOFF_MAG_24NA (0b00000100)
#define LOFF_MAG_6UA (0b00001000)
#define LOFF_MAG_24UA (0b00001100)
#define LOFF_FREQ_DC (0b00000000)
#define LOFF_FREQ_7p8HZ (0b00000001)
#define LOFF_FREQ_31p2HZ (0b00000010)
#define LOFF_FREQ_FS_4 (0b00000011)
#define PCHAN (0)
#define NCHAN (1)
#define OFF (0)
#define ON (1)

// used for channel settings
#define ACTIVATE_SHORTED (2)
#define ACTIVATE (1)
#define DEACTIVATE (0)

#define PCKT_START 0xA0	// prefix for data packet error checking
#define PCKT_END 0xC0	// postfix for data packet error checking

// daisy module
#define CLK_EN	5


#define SAMPLE_RATE_16kHZ		0x00  //(b00000000)	// 16kHz sample rate
#define SAMPLE_RATE_8kHZ		0x01  //(b00000001)	// 8kHz sample rate
#define SAMPLE_RATE_4kHZ		0x02  //(b00000010)	// 4kHz sample rate
#define SAMPLE_RATE_2kHZ		0x03  //(b01000011)	// 2kHz sample rate
#define SAMPLE_RATE_1kHZ		0x04  //(b00000100)	// 1kHz sample rate
#define SAMPLE_RATE_500HZ		0x05  //(b00000101)	// 500Hz sample rate
#define SAMPLE_RATE_250HZ		0x06  //(b00000110)	// 250Hz sample rate

//LIS3DH
#define READ_REG		0x80
#define READ_MULTI		0x40
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

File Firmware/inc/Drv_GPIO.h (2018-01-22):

/*
 * Drv_GPIO.h
 *
 *  Created on: 13/11/2015
 *      Author: alumno
 */

#ifndef DRV_GPIO_H_
#define DRV_GPIO_H_

#include "lpc_types.h"

/** @defgroup GPIO_Library
 *  @ingroup "Biopoteciales-LIRINS"
 *  Driver for controlling GPIO ports.
 *  @{
 */

//Declarations and definitions
#define GPIO_PORT0 0
#define GPIO_PORT1 1
#define GPIO_PORT2 2
#define GPIO_PORT3 3

/**
 * @brief Initialize GPIO port
 */
void Drv_GPIO_init();

/**
 * @brief De-Initialize GPIO port
 */
void Drv_GPIO_deInit();

/**
 * @brief Set a GPIO pin state
 * @param port Number of GPIO port 
 * @param pin Number of GPIO pin
 * @param state: TRUE for HIGH, FALSE for LOW
 */
void Drv_GPIO_setPinState(uint8_t port, uint8_t pin, bool state);

/**
 * @brief Get a GPIO pin state
 * @param port Number of GPIO port 
 * @param pin Number of GPIO pin
 * @return TRUE if the GPIO is HIGH, FALSE if LOW
 */
bool Drv_GPIO_getPinState(uint8_t port, uint8_t pin);

/**
 * @brief Set GPIO direction for a single GPIO pin
 * @param port Number of GPIO port 
 * @param pin Number of GPIO pin
 * @param output: TRUE for OUTPUT, FALSE for INPUT
 */
void Drv_GPIO_setPinDir(uint8_t port, uint8_t pin, bool output);

/**
 * @brief Get GPIO direction for a single GPIO pin
 * @param port Number of GPIO port 
 * @param pin Number of GPIO pin
 * @return TRUE in the GPIO is an OUTPUT, FALSE if INPUT
 */
bool Drv_GPIO_getPinDir(uint8_t port, uint8_t pin);

/**
 * @brief Toggle an individual GPIO output to the opposite state
 * @param port Number of GPIO port
 * @param pin Number of GPIO pin
 */
void Drv_GPIO_setPinToggle(uint8_t port, uint8_t pin);

/**
 * @}
 */


#endif /* DRV_GPIO_H_ */

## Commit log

2018-01-19 commit inicial de la placa PCB
    [ADS1299.sch, Aislación.sch, PonchoBiopotenciales.kicad_pcb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]
2018-01-21 agregado de archivos de fabricación
    [PonchoBiopotenciales-B.Cu.gbr, PonchoBiopotenciales-B.Mask.gbr, PonchoBiopotenciales-B.Paste.gbr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]
2018-01-22 se añadió la librería faltante
2018-01-27 BOMs agregados
    [PonchoBiopotenciales.csv]
2018-01-28 Listado de materiales con precios DIGIKEY 01/2018
    [ADS1299.sch, Aislación.sch, PonchoBiopotenciales.csv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]
2021-04-17 corregidos los slots de los ADUM
    [PonchoBiopotenciales-B.Cu.gbr, PonchoBiopotenciales-B.Paste.gbr, PonchoBiopotenciales-B.SilkS.gbr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]
